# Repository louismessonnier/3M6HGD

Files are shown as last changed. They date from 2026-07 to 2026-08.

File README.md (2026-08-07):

# 3H6MGD

A custom analog macropad for **Geometry Dash**, built around magnetic Hall-effect
switches for continuous key-travel sensing. The macroapd has three analog jump keys 
alongside six mechanical keys and a rotary encoder for volume control.

<p align="center">
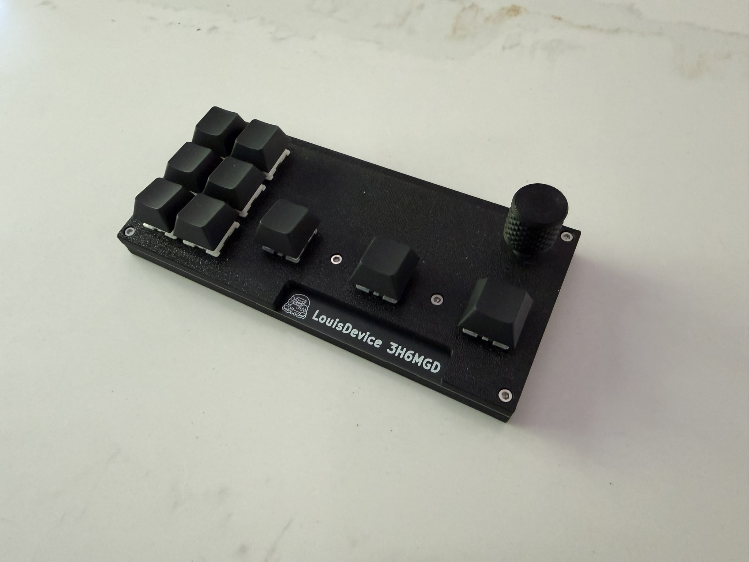
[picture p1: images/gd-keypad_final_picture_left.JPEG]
GD Keypad, left view
  
</p>

---

## Why analog switches

Most keyboards report a key as simply pressed or not pressed. Hall-effect
switches instead measure how far the key has travelled, by reading the field of
a magnet in the switch stem with a linear sensor on the PCB. That continuous
position enables features that matter in a timing-based game like Geometry Dash —
primarily **adjustable actuation** (choose exactly how far down counts as a press). 
This board brings that to a compact macropad.

## Features

- **3 analog Hall-effect jump keys** programmable with hmkconf
- **6 mechanical keys** in a diode matrix for non-jump inputs
- **Rotary encoder** mapped to per-application volume and mute for Geometry Dash
- **8 kHz USB polling** via the AT32F405's high-speed USB
- Runs [libhmk](https://github.com/peppapighs/libhmk): analog behaviour is
  configured live in the browser through [hmkconf](https://hmkconf.com/)
- USB-C, flashed over WebUSB DFU

## Hardware

- **MCU:** Artery AT32F405RCT7
- **Analog switches:** Wooting Lekker Tikken Medium, with MT9102ET linear Hall
  sensors (SOT-23-3) on the PCB
- **Mechanical switches:** MX switches on GATERON Upgrade Hot-swap PCB 2.0 Socket-KS-2P02B01-01-a
- **Rotary encoder:** Alps EC11E15244G1 30 detent with push switch
- **PCB:** 2-layer, 1.2 mm, designed in KiCad, manufactured by JLCPCB
- **Case:** two-piece sandwich, printed in PETG or PLA, with a printed knob

<p align="center">
  PCB, front
  PCB, back
</p>

## Firmware

The board runs [libhmk](https://github.com/peppapighs/libhmk). Everything about
the firmware (how the board is defined, the custom module that adds the
mechanical matrix and encoder, how to build and flash it, and the calibration and
volume-control setup) is in **[firmware/README.md](firmware/README.md)**.

## Repository layout

```
firmware/   libhmk keyboard definition, custom matrix + encoder module, build docs
kicad/      KiCad project (schematic and PCB)_
cad/        Case and knob models
images/     Renders and photos
docs/       Design notes and references
```

## Acknowledgements

This project builds on the open-source Hall-effect keyboard community:

- **[libhmk](https://github.com/peppapighs/libhmk)** and
  **[HE60](https://github.com/peppapighs/HE60)** by
  [peppapighs](https://github.com/peppapighs) - the firmware this board runs and
  the reference hardware it draws from
- **[marbastlib](https://github.com/ebastler/marbastlib)** by
  [ebastler](https://github.com/ebastler) - KiCad footprints for the Hall-effect
  and mechanical switches
- [Encoder Knob](https://www.thingiverse.com/thing:4206617) by V0lD, from Thingiverse, licensed CC BY-NC

## License

The firmware (`firmware/`) is licensed under **GNU General Public License v3.0**, inherited from
[libhmk](https://github.com/peppapighs/libhmk), on which it is based. The hardware
(`kicad/`) and case (`cad/`) files are licensed under **MIT License**. The encoder
knob is a third-party design under CC BY-NC 4.0 — see Acknowledgements.

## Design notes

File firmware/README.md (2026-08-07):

# Firmware

The board runs [libhmk](https://github.com/peppapighs/libhmk), an open-source
Hall-effect keyboard firmware, configured live through
[hmkconf](https://hmkconf.com/). On top of libhmk this board adds a small module
(`gd_keypad.c` / `.h`) for the six mechanical keys and the rotary encoder, which
libhmk does not model natively.

Files here:

| File | Role |
|---|---|
| `keyboard.json` | The board definition (libhmk compiles it into firmware, hmkconf reads it to draw the board) |
| `gd_keypad.c` / `gd_keypad.h` | Mechanical matrix scanning + rotary encoder decoding |
| `main.c` | The updates version of libhmk's `main.c` with a three-line change that calls the module |

---

## Building

libhmk is the build environment. Keep this repo separate from your libhmk clone
and copy these files in.

**One-time setup:**

1. Install [Python](https://www.python.org/downloads/) (tick "Add to PATH"),
   [Git](https://git-scm.com/), and [VS Code](https://code.visualstudio.com/)
2. In VS Code, install the **PlatformIO IDE** extension
3. Clone libhmk and install its dependency:
   ```
   git clone https://github.com/peppapighs/libhmk.git
   cd libhmk
   python -m pip install -r requirements.txt
   ```

**Add this board:**

1. Copy the files into the libhmk clone:
   - `keyboard.json` → `keyboards/gd-keypad/keyboard.json`
   - `gd_keypad.h` → `include/gd_keypad.h`
   - `gd_keypad.c` → `src/gd_keypad.c`
   - replace `src/main.c` with new `main.c` file (three lines patch - see below)
2. Open the `libhmk` folder in VS Code as the workspace root
3. In the terminal:
   ```
   python setup.py -k gd-keypad
   ```
   (no output means success - it writes `platformio.ini`)
4. Build with the checkmark in the status bar, or PlatformIO sidebar →
   Project Tasks → gd-keypad → Build
5. Output: `.pio/build/gd-keypad/firmware.bin`

The three-line `main.c` change - the module must run **after** `matrix_scan()`
(which would otherwise overwrite our keys with empty ADC data) and **before**
`layout_task()` (which turns key states into USB reports):

```diff
 #include "xinput.h"
+#include "gd_keypad.h"
```
```diff
   matrix_init();
+  gd_keypad_init();
```
```diff
     matrix_scan();
+    gd_keypad_task();
     layout_task();
```

Re-apply this patch whenever you pull libhmk updates.

## Flashing (WebUSB DFU)

1. Hold the **BOOT0** button, plug in USB, release BOOT0
2. **First time on Windows:** the device shows up as "DFU in FS Mode" under
   *Other devices* in Device Manager with no driver. Install one with
   [Zadig](https://zadig.akeo.ie/): Options → List All Devices, select
   "DFU in FS Mode", target **WinUSB**, Install Driver.
3. Open the [WebUSB DFU tool](https://devanlai.github.io/webdfu/dfu-util/) in
   Chrome or Edge → Connect → select the **internal flash** interface → choose
   `firmware.bin` → flash.
4. Unplug and replug **without** BOOT0 to boot the firmware. It enumerates as
   "GD Keypad".

## Configuring in hmkconf

[hmkconf](https://hmkconf.com/) talks to the running board over WebUSB (plugged
in normally, not in DFU) and edits the config in flash — no reflashing. All
twelve keys, including the encoder, appear there and can be remapped. Settings
persist in flash and survive reflashing.

---

## How it works

### The board definition (`keyboard.json`)

libhmk builds a board from one JSON file; the driver and chip support are shared
code selected by `"driver": "at32f405xx"`.

Key fields for this board:

- `usb.port: "hs"` — high-speed USB, which is what enables 8 kHz polling
- `hardware.hse_value: 12000000` — the 12 MHz crystal the USB PHY requires
- `keyboard.num_keys: 12` — sizes every per-key array at compile time
  (see below for why it's 12, not 3)
- `analog.raw` — maps the three sensors directly to ADC pins A0/A1/A2, no
  multiplexer:
  ```json
  "raw": { "input": ["A0", "A1", "A2"], "vector": [3, 2, 1] }
  ```
  The reversed vector puts the physically-leftmost key first, matching the board.
- `calibration` — global starting values for the noise floor and bottom-out
  threshold; libhmk auto-calibrates each key at runtime relative to these

### Adding the mechanical keys and encoder

libhmk's key pipeline has a natural seam: everything upstream decides whether a
key is down and writes `key_matrix[i].is_pressed`; everything downstream
(`layout_task()`) turns that boolean into keycodes, layers, and USB reports. And
`layout_task()` is **edge-triggered** — it only acts on changes to those
booleans.

That made the integration clean. Rather than hand-build keypresses, `num_keys` is
set to **12** and the module writes directly into the extra indices:

| Index | Input |
|---|---|
| 0–2 | Hall jump keys (libhmk, from the ADC) |
| 3–8 | Mechanical matrix |
| 9 | Encoder push switch |
| 10 / 11 | Encoder rotate CW / CCW (virtual) |

The mechanical keys and encoder become first-class keys — same code path as the
analog ones, fully remappable in hmkconf. Keys 3–11 have no ADC input, so their
sensor values stay 0 and they never self-actuate; the module's write is what
gives them state.

### The mechanical matrix

The diodes point toward the rows, so the scan **drives a row low and reads the
columns** (each with an internal pull-up). A pressed key pulls its column low
through the forward-biased diode. One row is active at a time; the diodes prevent
ghosting. Each switch is debounced with a "wait for the reading to hold steady
for 5 ms" filter.

### The encoder

A quadrature encoder's two contacts produce a repeating pattern as it turns;
direction comes from *which* transition occurs. The module reads both pins,
combines previous and current state into a lookup that yields −1 / 0 / +1, and
accumulates to a detent. Because a rotation is an event but `layout_task()` only
understands press and release, each detent briefly presses and then releases a
virtual key — serialized so a fast spin produces a clean sequence of discrete
keypresses rather than one smeared hold.

---

## Per-application volume control (AutoHotkey)

The encoder drives *Geometry Dash's* volume specifically — not system volume —
because Windows has no per-app volume shortcut. The board sends F13/F14 (rotation)
and F15 (press); a script translates those into per-app audio commands.

1. Install [SoundVolumeView from NirSoft](https://www.nirsoft.net/utils/sound_volume_view.html)
   and unzip to somewhere permanent (e.g. `C:\Program Files\SoundVolumeView`)
2. Open Geometry Dash
3. Run `SoundVolumeView.exe` and confirm that `GeometryDash.exe` is an entry
4. Install [AutoHotkey](https://www.autohotkey.com/)
5. Make a text file named `gd-knob.ahk` anywhere convenient
6. Open `gd-knob.ahk` in Notepad and paste the following (replace `1` / `-1` with
   your preferred step size):

   ```autohotkey
   #Requires AutoHotkey v2.0

   svv := "C:\Program Files\SoundVolumeView\SoundVolumeView.exe"
   app := "GeometryDash.exe"

   F14::Run(svv ' /ChangeVolume "' app '" 1', , "Hide")   ; knob CW  = louder
   F13::Run(svv ' /ChangeVolume "' app '" -1', , "Hide")  ; knob CCW = quieter
   F15::Run(svv ' /Switch "' app '"', , "Hide")           ; knob press = mute toggle
   ```

7. Run it by double-clicking `gd-knob.ahk` and test the knob
8. To launch it with Windows: Win+R, type `shell:startup`, press Enter (opens the
   Startup folder), then put a shortcut to `gd-knob.ahk` there (right-click the
   `.ahk`, Create shortcut, move the shortcut into that folder)

F13–F15 were chosen because effectively no keyboard has them, so they don't
collide with anything else while the script captures them.

---

## Calibration

The Hall keys need calibrating once the switches are seated in the case (their
resting magnet-to-sensor distance, which the calibration depends on, is only
fixed once the case holds them at the proper height). hmkconf has a calibration
section where the sensors can be tuned.

---

## Notes
- `gd_keypad.c` / `.h` are written against libhmk (GPL-3.0-or-later) and inherit
  that license.

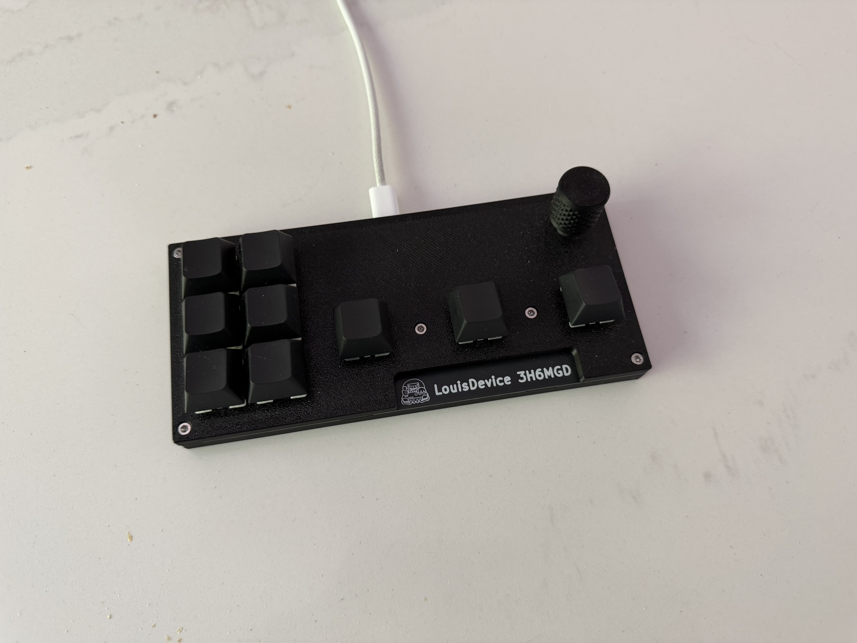
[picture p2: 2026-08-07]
images/gd-keypad_final_picture_right.JPEG

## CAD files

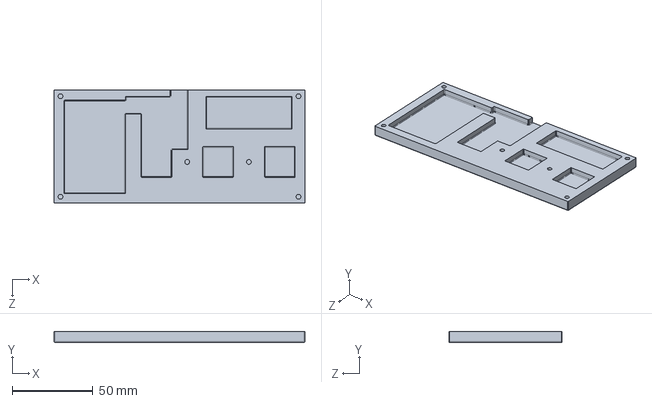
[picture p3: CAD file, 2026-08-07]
cad/gd-keypad-case_v1/gd-keypad_bottom-case.SLDPRT
155.0 x 6.75 x 70.0 mm

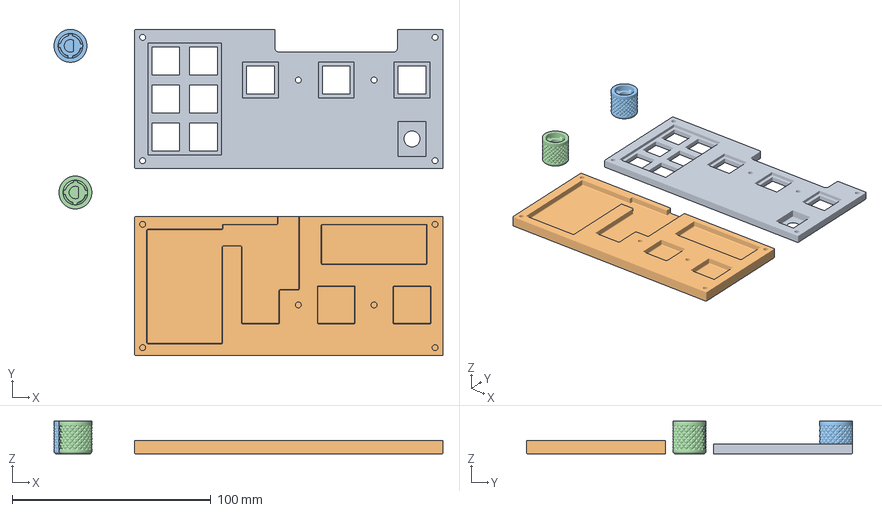
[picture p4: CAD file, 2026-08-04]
cad/gd-keypad_print-files/gd-keypad_case_print6.3mf
195.6 x 164.0 x 16.6 mm
gd-keypad_top-case.STL
gd-keypad_bottom-case.STL
16mm_3mm_D.stl x 2

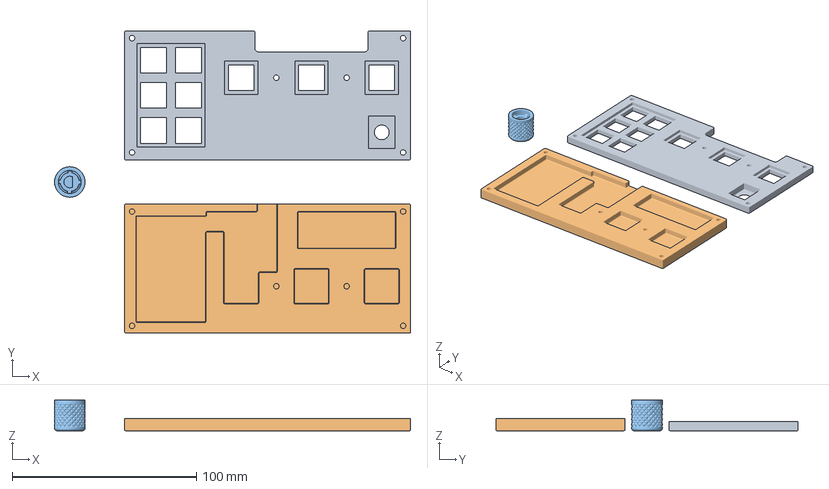
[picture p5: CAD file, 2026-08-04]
cad/gd-keypad_print-files/gd-keypad_case_print5.3mf
193.0 x 164.0 x 16.6 mm
gd-keypad_top-case.STL
gd-keypad_bottom-case.STL
16mm_3mm_D.stl

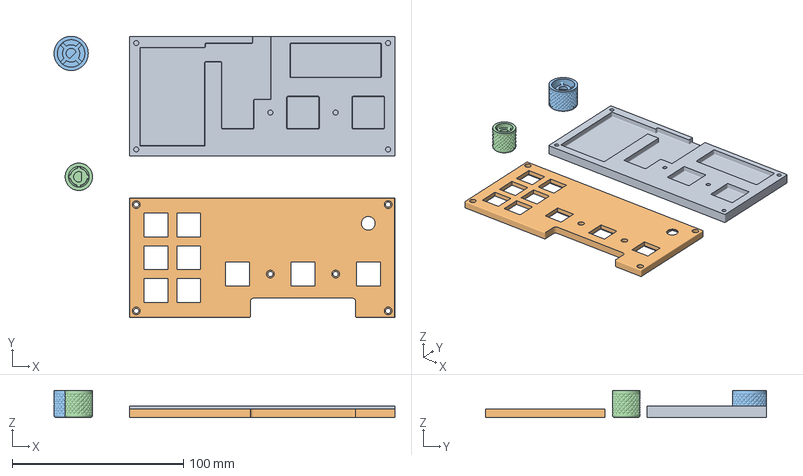
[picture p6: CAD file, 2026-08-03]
cad/gd-keypad_print-files/gd-keypad_case_print2.3mf
199.0 x 164.2 x 16.0 mm
gd-keypad_bottom-case.STL
gd-keypad_top-case.STL
20mm_D.stl
16mm_3mm_D.stl

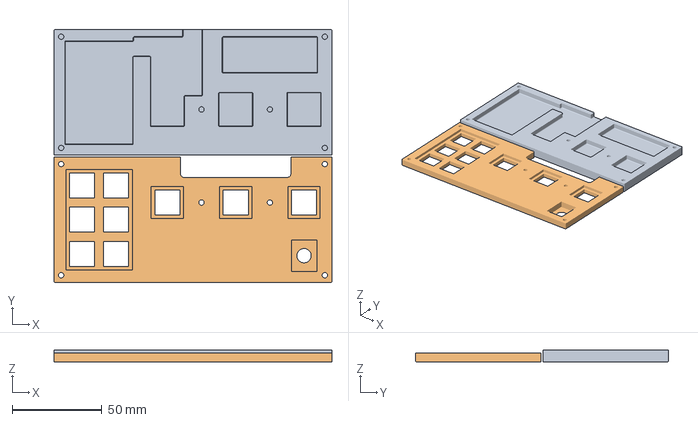
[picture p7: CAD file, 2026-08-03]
cad/gd-keypad_print-files/gd-keypad_case_print1.3mf
155.0 x 141.0 x 6.75 mm
gd-keypad_bottom-case.STL
gd-keypad_top-case.STL

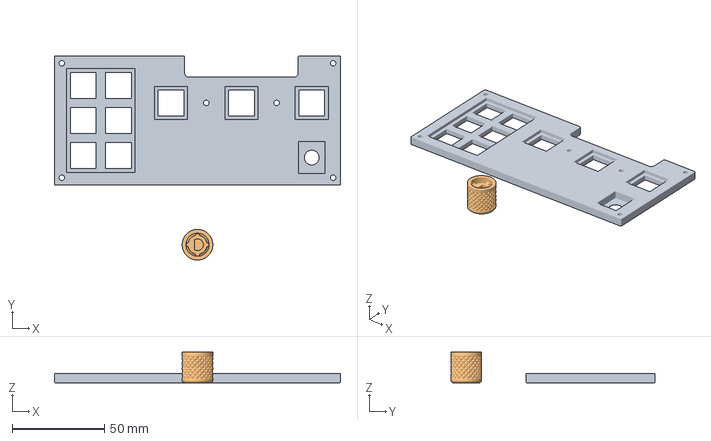
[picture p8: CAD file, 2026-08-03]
cad/gd-keypad_print-files/gd-keypad_case_print3.3mf
155.0 x 110.6 x 16.6 mm
gd-keypad_top-case.STL
16mm_3mm_D.stl

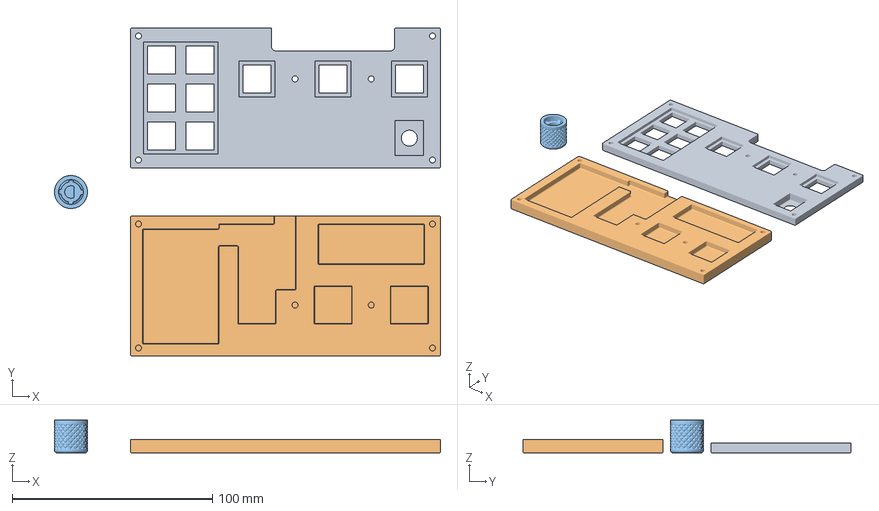
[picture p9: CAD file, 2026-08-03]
cad/gd-keypad_print-files/gd-keypad_case_print4.3mf
193.0 x 164.0 x 16.5 mm
gd-keypad_top-case.STL
gd-keypad_bottom-case.STL
16mm_3mm_D.stl

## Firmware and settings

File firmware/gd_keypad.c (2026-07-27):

/*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
 * You should have received a copy of the GNU General Public License along with
 * this program. If not, see <https://www.gnu.org/licenses/>.
 */

#include "gd_keypad.h"

#include "hardware/hardware.h"
#include "matrix.h"

#include "at32f402_405.h"

_Static_assert(NUM_KEYS == 12, "GD Keypad expects num_keys = 12");

//--------------------------------------------------------------------+
// Pin map
//--------------------------------------------------------------------+
//
// Diodes point toward the rows (current flows column -> row), so we drive a
// row LOW and read the columns with pull-ups. A pressed key pulls its column
// low through the forward-biased diode.

#define GD_NUM_ROWS 3
#define GD_NUM_COLS 2
#define GD_NUM_MECH (GD_NUM_ROWS * GD_NUM_COLS)

// ROW 0 = PB0, ROW 1 = PC5, ROW 2 = PC4
static gpio_type *const row_ports[GD_NUM_ROWS] = {GPIOB, GPIOC, GPIOC};
static const uint16_t row_pins[GD_NUM_ROWS] = {
    GPIO_PINS_0,
    GPIO_PINS_5,
    GPIO_PINS_4,
};

// COLUMN 0 = PA6, COLUMN 1 = PA5
static gpio_type *const col_ports[GD_NUM_COLS] = {GPIOA, GPIOA};
static const uint16_t col_pins[GD_NUM_COLS] = {
    GPIO_PINS_6,
    GPIO_PINS_5,
};

// ENCODER A = PF4, ENCODER B = PF5, ENCODER S1 = PA3
#define GD_ENC_A_PORT GPIOF
#define GD_ENC_A_PIN GPIO_PINS_4
#define GD_ENC_B_PORT GPIOF
#define GD_ENC_B_PIN GPIO_PINS_5
#define GD_ENC_SW_PORT GPIOA
#define GD_ENC_SW_PIN GPIO_PINS_3

//--------------------------------------------------------------------+
// State
//--------------------------------------------------------------------+

// Debounced state of the six mechanical keys plus the encoder switch
#define GD_NUM_DEBOUNCED (GD_NUM_MECH + 1)
#define GD_IDX_ENC_SW GD_NUM_MECH

static bool sw_stable[GD_NUM_DEBOUNCED];
static bool sw_last_raw[GD_NUM_DEBOUNCED];
static uint32_t sw_last_change[GD_NUM_DEBOUNCED];

// Quadrature decoder. Index is (previous_state << 2) | current_state, where
// state is (A << 1) | B. Zero entries are no-ops or invalid double
// transitions, which we ignore rather than guess at.
static const int8_t enc_lut[16] = {
    0, -1, +1, 0, +1, 0, 0, -1, -1, 0, 0, +1, 0, +1, -1, 0,
};

static uint8_t enc_prev_state;
static int32_t enc_accum;

// Deadline for the currently held virtual rotate key, 0 when idle
static uint32_t enc_pulse_until;
static uint8_t enc_pulse_key;

//--------------------------------------------------------------------+
// Helpers
//--------------------------------------------------------------------+

/**
 * @brief Short busy-wait to let a row line settle after being driven
 *
 * The column pull-ups are weak (tens of kohm), so the line needs a moment to
 * discharge through a pressed key before we sample it.
 */
static void gd_settle(void) {
  for (volatile uint32_t i = 0; i < 256; i++) {
  }
}

/**
 * @brief Debounce one switch and publish it to the key matrix
 *
 * @param idx Index into the debounce arrays
 * @param raw Raw reading, true when pressed
 * @param key Key index to write in key_matrix
 */
static void gd_debounce(uint32_t idx, bool raw, uint8_t key) {
  if (raw != sw_last_raw[idx]) {
    // Reading changed, restart the debounce window
    sw_last_raw[idx] = raw;
    sw_last_change[idx] = timer_read();
  } else if ((raw != sw_stable[idx]) &&
             (timer_elapsed(sw_last_change[idx]) >= GD_DEBOUNCE_MS)) {
    // Reading has been consistent for long enough, accept it
    sw_stable[idx] = raw;
  }

  key_matrix[key].is_pressed = sw_stable[idx];
}

//--------------------------------------------------------------------+
// Init
//--------------------------------------------------------------------+

void gd_keypad_init(void) {
  gpio_init_type gpio_init_struct;

  crm_periph_clock_enable(CRM_GPIOA_PERIPH_CLOCK, TRUE);
  crm_periph_clock_enable(CRM_GPIOB_PERIPH_CLOCK, TRUE);
  crm_periph_clock_enable(CRM_GPIOC_PERIPH_CLOCK, TRUE);
  crm_periph_clock_enable(CRM_GPIOF_PERIPH_CLOCK, TRUE);

  // Rows: push-pull outputs, idle high
  for (uint32_t i = 0; i < GD_NUM_ROWS; i++) {
    gpio_default_para_init(&gpio_init_struct);
    gpio_init_struct.gpio_pins = row_pins[i];
    gpio_init_struct.gpio_mode = GPIO_MODE_OUTPUT;
    gpio_init_struct.gpio_out_type = GPIO_OUTPUT_PUSH_PULL;
    gpio_init_struct.gpio_pull = GPIO_PULL_NONE;
    gpio_init_struct.gpio_drive_strength = GPIO_DRIVE_STRENGTH_STRONGER;
    gpio_init(row_ports[i], &gpio_init_struct);

    gpio_bits_write(row_ports[i], row_pins[i], TRUE);
  }

  // Columns: inputs with pull-ups
  for (uint32_t i = 0; i < GD_NUM_COLS; i++) {
    gpio_default_para_init(&gpio_init_struct);
    gpio_init_struct.gpio_pins = col_pins[i];
    gpio_init_struct.gpio_mode = GPIO_MODE_INPUT;
    gpio_init_struct.gpio_pull = GPIO_PULL_UP;
    gpio_init(col_ports[i], &gpio_init_struct);
  }

  // Encoder A/B and the push switch: inputs with pull-ups. The encoder's
  // common pin and the switch's second pin are tied to ground on the PCB.
  gpio_default_para_init(&gpio_init_struct);
  gpio_init_struct.gpio_pins = GD_ENC_A_PIN | GD_ENC_B_PIN;
  gpio_init_struct.gpio_mode = GPIO_MODE_INPUT;
  gpio_init_struct.gpio_pull = GPIO_PULL_UP;
  gpio_init(GPIOF, &gpio_init_struct);

  gpio_default_para_init(&gpio_init_struct);
  gpio_init_struct.gpio_pins = GD_ENC_SW_PIN;
  gpio_init_struct.gpio_mode = GPIO_MODE_INPUT;
  gpio_init_struct.gpio_pull = GPIO_PULL_UP;
  gpio_init(GD_ENC_SW_PORT, &gpio_init_struct);

  // Seed the debounce state from the current readings so we do not report a
  // spurious press on the first scan.
  const uint32_t now = timer_read();
  for (uint32_t i = 0; i < GD_NUM_DEBOUNCED; i++) {
    sw_stable[i] = false;
    sw_last_raw[i] = false;
    sw_last_change[i] = now;
  }

  // Seed the quadrature state so the first read is not treated as a step
  const uint8_t a =
      (gpio_input_data_bit_read(GD_ENC_A_PORT, GD_ENC_A_PIN) == SET) ? 1u : 0u;
  const uint8_t b =
      (gpio_input_data_bit_read(GD_ENC_B_PORT, GD_ENC_B_PIN) == SET) ? 1u : 0u;
  enc_prev_state = (uint8_t)((a << 1) | b);
  enc_accum = 0;

  enc_pulse_until = 0;
  enc_pulse_key = 0;

  for (uint32_t i = GD_KEY_MECH_FIRST; i < NUM_KEYS; i++)
    key_matrix[i].is_pressed = false;
}

//--------------------------------------------------------------------+
// Task
//--------------------------------------------------------------------+
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

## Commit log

2026-08-03 create 3d print project files for each print completed
    [gd-keypad_case_print1.3mf, gd-keypad_case_print2.3mf, gd-keypad_case_print3.3mf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]
2026-08-04 create print file for 5th print
    [gd-keypad_case_print5.3mf]
2026-08-04 create 6th print file
    [gd-keypad_case_print6.3mf]
2026-08-07 add images of final assembled design
2026-08-07 update bottom case cad
    [gd-keypad_bottom-case.SLDPRT]

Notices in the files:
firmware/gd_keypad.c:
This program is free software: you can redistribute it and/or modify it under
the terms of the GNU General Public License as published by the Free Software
